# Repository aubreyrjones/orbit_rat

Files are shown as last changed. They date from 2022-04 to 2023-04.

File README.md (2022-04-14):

Orbit Rat
---------
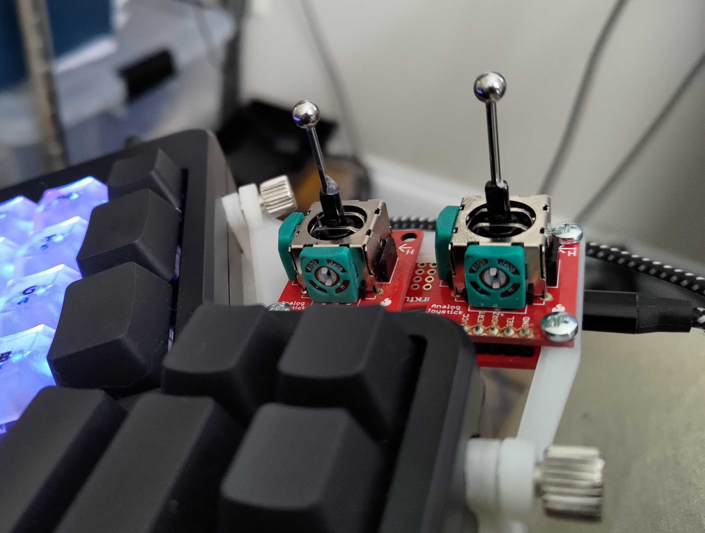
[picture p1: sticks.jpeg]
Orbit Rat prototype


[Watch a demo](https://www.youtube.com/watch?v=k3nQiXu3pM4)

THIS IS NOT A MOUSE REPLACEMENT. The Orbit Rat is a Teensy LC based PC input device designed
to facilitate panning and orbiting in CAD and graphic design software.

The concept is similar to the 3dconnexion navigation device. But the Orbit Rat has fewer 
degrees of freedom, much wider compatibility, and much lower cost. The Orbit Rat is not 
quite a space mouse, you see.

The OR is designed around a pair of small joysticks, like those on a gamepad controller. These 
joysticks then control pan and orbit in CAD, art, and graphic design programs by specially
emulating a mouse. _No special drivers or plugins needed_, works in any operating system.

This is not a regular joystick-controlled mouse. OR implements a special "rewind" operation
after every motion, which resets the mouse cursor position and unlocks near-infinite pan/orbit 
in any program that uses middle-click and drag for pan.

The cost to build one is around $30 USD. You could build it without any soldering, using
breadboard, but it will be bulky. You can easily solder it on protoboard with hand wiring.
It's also an easy circuit board to design.

Tested on Linux and Windows. Should work on Mac and mobile OS as well.

Tested to work with default settings in:

* Fusion 360
* Inkscape
* GIMP
* EAGLE CAD

# How it Works

This is pretty configurable, but by default...

When you tilt the stick outside the deadzone, Orbit Rat emulates a mouse holding down the middle
mouse button and starting a drag motion. This starts a pan action in lots of CAD and art software. 
The viewport will move as if you're panning with the mouse so long as you're tiling the stick.

If you think about how your favorite software works, when you finish the pan motion and let go the button,
the mouse is in a different part of the screen than when you started. You have to 
move the cursor back toward the middle of the screen to get more space if you want to continue the pan. 
With a traditional joystick-controlled mouse, this is torture.

But not so with Orbit Rat.

As you move, the OR tracks how much mouse motion it has sent to your computer. When you let
go of the stick, it very quickly moves the cursor back to where it was when you first tilted the stick. 
You can now continue the pan just by tilting the stick again. Or, you can continue your work 
with the cursor just where you left it.

The other stick works very similarly, but also emulates holding down the left shift keyboard button. 
This will activate an orbit in CAD software.

This is almost as much control as a dedicated "3d mouse" with special driver support. The beauty of 
Orbit Rat is that it works everywhere, in any operating system, in any application that uses click 
and drag for pan.

It can also do other stuff, like sending scroll wheel events and keyboard keys... but the rewind
operation is what it does uniquely.

# Features

* User defined list of stick modes and parameters to use. As many as you like until
  you run out of RAM. Most of what's discussed below can be set per mode.

* Cycle through your defined modes by clicking the stick buttons.

* REWIND - stick initiates a mouse movement, then OR returns the cursor to its starting
  position when you let go of the stick.

* STUTTER - similar to rewind mode, but continually moves a set distance, rewinds, then 
  repeats as long as you hold down the button. Not smooth, but allows "infinite" scrolling
  with limited screen real estate.

* SIMPLE - just be a mouse cursor, no rewind.

* SCROLL - stick movement sends scroll wheel commands. Useful for CAD zoom, or
  document scrolling.

* User-defined stick curves, so you can tweak the sensitivity of each stick.

* Invert or ignore any stick axis.

* Choose mouse button(s) and/or keyboard key that is held during mouse motion.

* Auto-calibrates joysticks by default (although not perfectly)

* Configurable to send HID joystick events if desired for custom application code.

* Parts are available circa Q2 2022. Teensy LC available despite chip shortage. 
  Joysticks and other parts available from hobby electronics suppliers (Sparkfun, 
  Adafruit).

# _Planned_ Features

* RGB status LEDs (DotStar) for each stick's modes
* PCB reference design
* Left-handed PCB design

# Limitations

The Orbit Rat is fundamentally impersonating a mouse, so it doesn't have access to any
information a regular dumb mouse wouldn't have. It doesn't get any feedback from the 
operating system.

The main place this shows up is when the cursor hits the edge of the screen during a move.
The Orbit Rat thinks it's still moving the cursor, but the OS doesn't let it leave the screen.
When the OR goes to rewind the cursor motion at the end of the move, it has the wrong
idea of how much to rewind and overshoots.

Additionally, moue wheel scrolling in Linux and Windows is _not_ smooth. It goes in
chunky, discrete increments. Orbit Rat tries its best to send scroll events at a steady
rate, but without special drivers, it can't make the screen animation smooth when
scrolling (like e.g. Apple trackpad scrolling).

# Configuration and Building

Since you need the tools to upload the firmware anyway, I made things easy for me.
Orbit Rat is configured in source code and built with [PlatformIO](https://platformio.org/).

The easiest way to use PlatformIO is just to use VisualStudio Code (not Visual Studio) with
the free PlatformIO plugin from the marketplace. Standalone setups may work but I haven't
tested them.

When you first build, it may seem to stall for a very long time. PlatformIO is downloading a newer
compiler from a very slow connection. It gives no progress indicator. It seriously
took me 20 minutes to download. This only happens the first time you build. It also
may finish the download, try to compile, then say it failed... try again before
concluding it doesn't work.

Configuration is at the top of `main.cpp`. You can learn more about the options in 
`config_types.hpp`.

On your operation system you will need to set the "Teensyduino OrbitRat Mouse" acceleration
to 0. If you don't, the cursor will not return to the correct location. You should be able
to leave acceleration on for your regular mouse however you like it.

## Hardware

This isn't commercial hardware or software. You'll need to cobble together your
own hardware setup.

I'm using a Teensy LC as my microcontroller. I expect Teensy 4.0 would work, but
little is gained from its expanded capabilities. Teensy 3 might work; Teensy 2
is not compatible.

Assuming you'll use the software mostly unmodified, you need to hook up a pair of
potentiometer joysticks to the Teensy's analog inputs. That's pretty much it.

For the prototype I used the model of joystick sold on SparkFun, along with their 
breakout boards. I wired up the axes directly to the Teensy LC analog pins. I added 
pullup resistors on the switches There are internal pullups that could work, but I 
didn't test that way.

You can see my pin assignments in `main.cpp` under `axisPins` and `buttonPins`.
That's also where you can alter them if you'd like to wire the pins up differently.
Note that you _must_ use analog inputs for the joysticks.

## Software

The software isn't written to be especially efficient. It's written for a Teensy LC,
which has a 48MHz core clock. I haven't noticed that input rates are too low, so
I don't worry about a bit of fake floating point.

Calibration is quasi-automatic right now (although you can turn it off). By default, 
the center point is read at startup. Conservative endpoints are taken as a default,
but will expand if they receive a higher value from the hardware during operation. You 
can turn off both these features at the top of `main.cpp`.

## Troubleshooting

> Problem: I flashed the firmware and plugged it into the computer, but my mouse doesn't 
work or moves erratically.

This is "normal" if you flash the Teensy with Orbit Rat firmware, but have not attached
the joysticks to it. Without the joysticks, the Teensy input voltages drift randomly
and result in erratic movement. Ideally, install both joysticks. If you need just
one joystick for some reason, adjust `n_axes` to equal `2` and fix the resultant
compile errors.

## This is not a commercial venture, and the Orbit Rat is not for sale

The whole point of the project is that it's very, very cheap compared to the pro-grade
alternative. Stocking the parts, assembling them, and shipping them takes time
I have no interest in spending. And people have expectations of commercial products
(warranties, returns, etc.) that I don't want to deal with. I have a job, and a
few bucks just isn't worth the hassle.

To make it worth it to me, each unit would need to sell for $100 or more. And
that kind of defeats the purpose.

On the other hand, this is also an absolutely _ideal_ first microcontroller project.
You can build a completely decent version using just breakout- and bread-boards.
It is within your abilities to Orbit Rat. I believe in you.

You can also try one of the circuit boards from the `circuits` directory.
Most of those designs aren't tested, but they're a good starting point for
your design. When I get a design printed and tested, I will mark it 
conspicuously.

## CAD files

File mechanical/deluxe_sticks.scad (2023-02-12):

$fn = 80;

bottom_height = 2;
main_height = 14;

clearance_diam = 5;
bottom_diam = 5;
top_diam = 12;
ball_diam = top_diam;
top_height = 12 - (ball_diam / 2);

stem_width = 1.85;
stem_thickness = 1.15;
stem_depth = 5;
stem_slop = 1.05;

module stick() {
difference() {
    union() {
        cylinder(bottom_height, d1= clearance_diam, d2 = bottom_diam);
        translate([0, 0, bottom_height])
            cylinder(main_height, d1 = bottom_diam, d2 = top_diam);
        translate([0, 0, main_height + bottom_height]) {
            cylinder(top_height, d = top_diam);
        }
        translate([0, 0, main_height + top_height + bottom_height]) {
            sphere(d = ball_diam);
        }
    }
    
    union() {
        translate([0, 0, stem_depth / 2]) 
            cube([stem_width * stem_slop, stem_thickness * stem_slop, stem_depth * 1.05], center = true);
    }
} 
}

$start_radius = 0.5;
$tip_radius = 0.2;
$tip_height = 1;
$full_support_height = 0.42;
$debug_supports = false;
$base_radius = $debug_supports ? $start_radius : $start_radius * 6.5;



module one_support(position, height) {
    transition_point = height - $tip_height;
    color([1, 0, 0]) union() {
        translate(position) {
            cylinder(0.20, $base_radius, $base_radius, false);
            cylinder(transition_point, $start_radius, $start_radius, false);
            translate([0, 0, transition_point]) {
                cylinder($tip_height, $start_radius, $tip_radius, false);
            }
        }
    }
}

support_height = 3;
s_off = (bottom_diam / 2) - ($tip_radius * 2);

stick();

//union() {
//    stick();
//    translate([0, 0, -support_height]) {
//        for (x = [-1.35, 1.35]) {
//            for (y = [-1.35, 1.35]) {
//                one_support([x, y], support_height);
//            }
//        }
//        one_support([0, s_off], support_height);
//        one_support([0, -s_off], support_height);
//        one_support([s_off, 0], support_height);
//        one_support([-s_off, 0], support_height);
//    }
//}

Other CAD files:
mechanical/plastic_sticks.scad

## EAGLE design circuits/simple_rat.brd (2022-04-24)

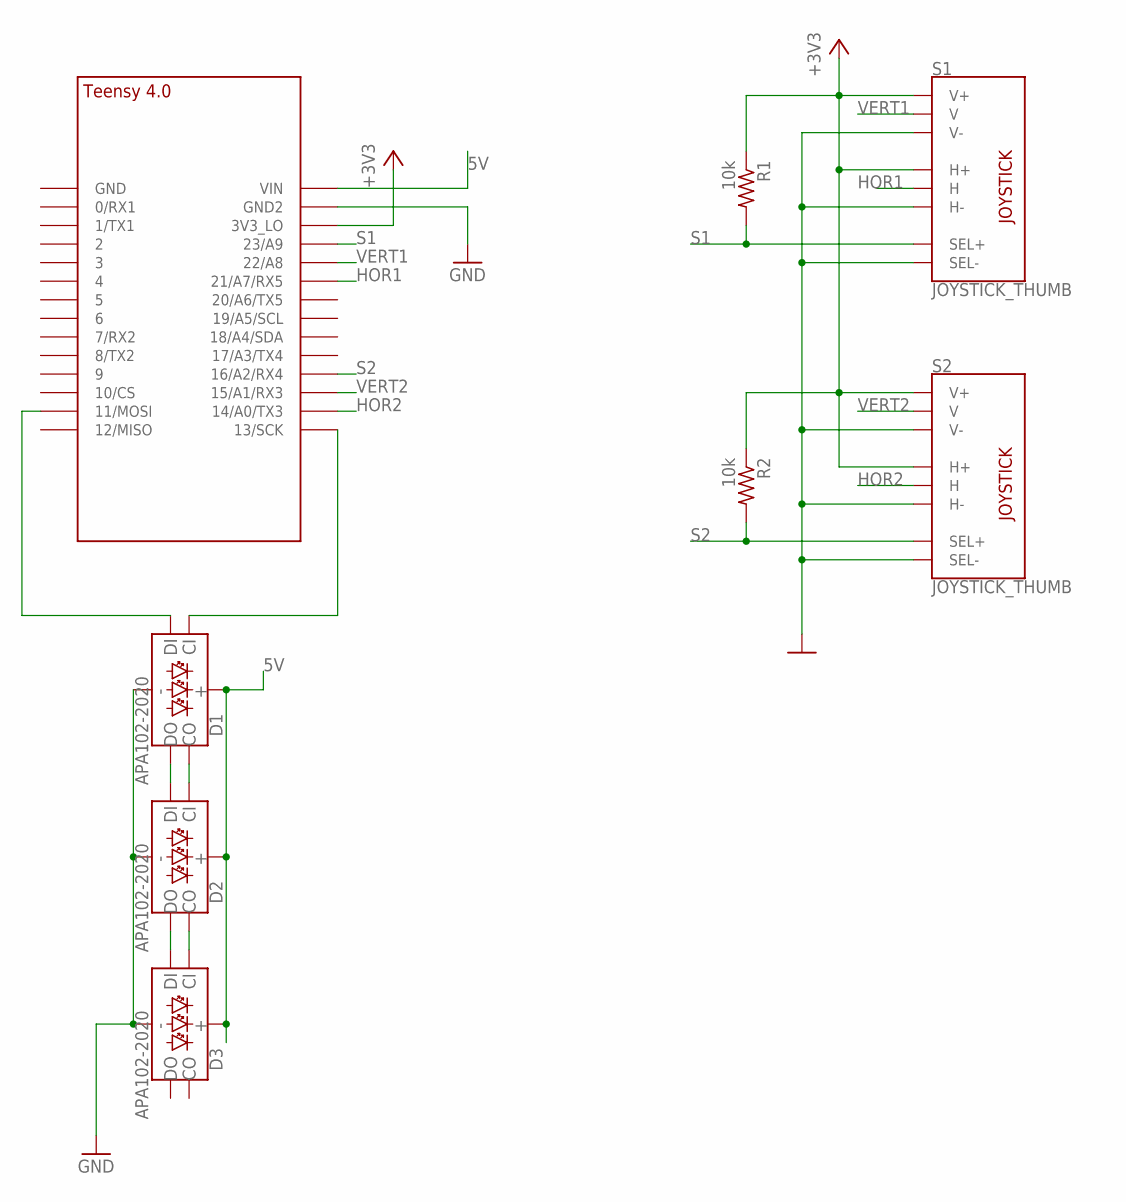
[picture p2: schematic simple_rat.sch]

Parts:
D1, D2, D3: APA102-2020
MCU: TEENSY_4.0-NOBOTTOM
R1, R2: 10k; R0603
S1, S2: JOYSTICK_THUMB; JOYSTICK

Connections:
5V: D1.5V_VIA (VCC), D1.VDD (VCC), D2.5V_VIA (VCC), D2.VDD (VCC), D3.5V_VIA (VCC), D3.VDD (VCC), MCU.VIN
+3V3: MCU.3V3_LO, R1.1, R2.1, S1.H1 (H+), S1.V1 (V+), S2.H1 (H+), S2.V1 (V+)
GND: D1.GND, D1.GND_VIA (GND), D2.GND, D2.GND_VIA (GND), D3.GND, D3.GND_VIA (GND), MCU.GND2, S1.B2A (SEL-), S1.H3 (H-), S1.V3 (V-), S2.B2A (SEL-), S2.H3 (H-), S2.V3 (V-)
HOR1: MCU.21/A7 (21/A7/RX5), S1.H2 (H)
HOR2: MCU.14/A0 (14/A0/TX3), S2.H2 (H)
unnamed: D1.SDO (DO), D2.SDI (DI)
unnamed: D1.CKO (CO), D2.CKI (CI)
unnamed: D2.SDO (DO), D3.SDI (DI)
unnamed: D2.CKO (CO), D3.CKI (CI)
unnamed: D1.CKI (CI), MCU.13/SCK
unnamed: D1.SDI (DI), MCU.11/MOSI
S1: MCU.23/A9, R1.2, S1.B1A (SEL+)
S2: MCU.16/A2 (16/A2/RX4), R2.2, S2.B1A (SEL+)
VERT1: MCU.22/A8, S1.V2 (V)
VERT2: MCU.15/A1 (15/A1/RX3), S2.V2 (V)

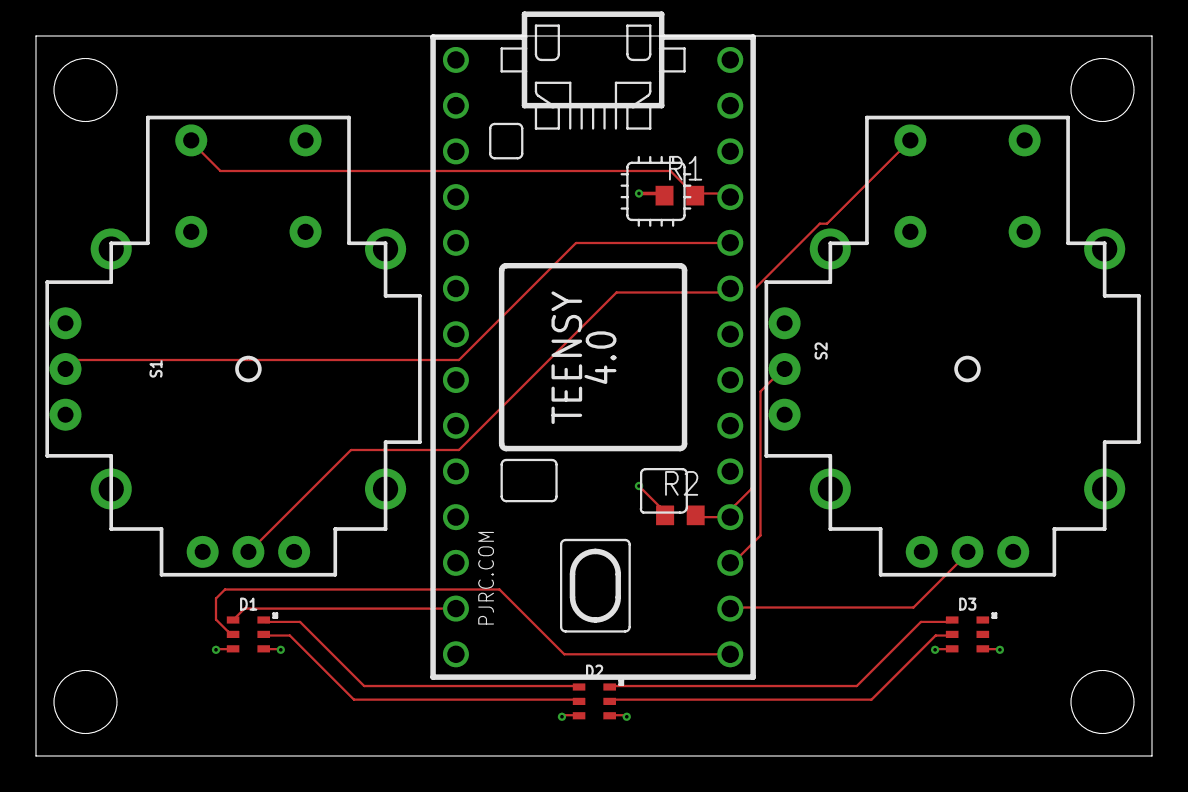
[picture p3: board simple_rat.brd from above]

Board: 4 copper layers, 62.0 x 40.0 mm, 8 parts (0 on the bottom side), 15 nets.

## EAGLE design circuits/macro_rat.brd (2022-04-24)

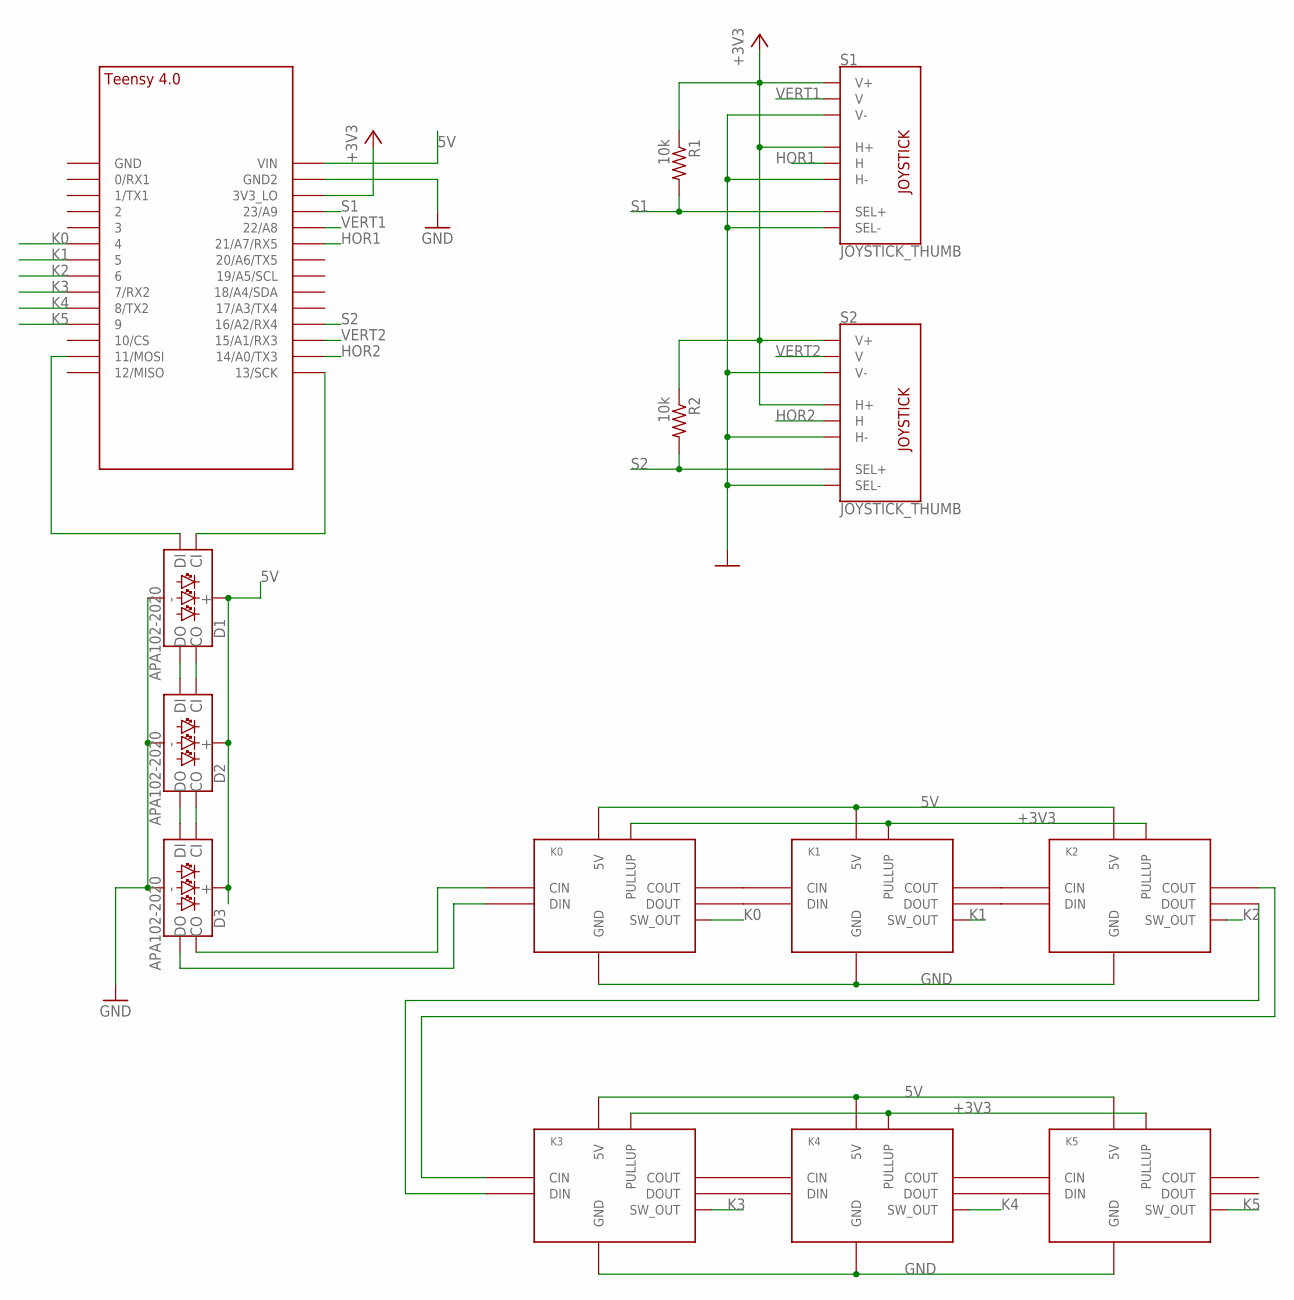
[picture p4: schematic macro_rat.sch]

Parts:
D1, D2, D3: APA102-2020
K0, K1, K2, K3, K4, K5: KEY_LED_CHOC_ONESIDERIGHT_HAND; KEY_CHOC_V2_RH
MCU: TEENSY_4.0-NOBOTTOM
R1, R2: 10k; R0603
S1, S2: JOYSTICK_THUMB; JOYSTICK

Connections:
5V: D1.5V_VIA (VCC), D1.VDD (VCC), D2.5V_VIA (VCC), D2.VDD (VCC), D3.5V_VIA (VCC), D3.VDD (VCC), K0.5V, K0.VDD (5V), K1.5V, K1.VDD (5V), K2.5V, K2.VDD (5V), K3.5V, K3.VDD (5V), K4.5V, K4.VDD (5V), K5.5V, K5.VDD (5V), MCU.VIN
+3V3: K0.PULLUP_V (PULLUP), K0.PULLUP_VIA (PULLUP), K1.PULLUP_V (PULLUP), K1.PULLUP_VIA (PULLUP), K2.PULLUP_V (PULLUP), K2.PULLUP_VIA (PULLUP), K3.PULLUP_V (PULLUP), K3.PULLUP_VIA (PULLUP), K4.PULLUP_V (PULLUP), K4.PULLUP_VIA (PULLUP), K5.PULLUP_V (PULLUP), K5.PULLUP_VIA (PULLUP), MCU.3V3_LO, R1.1, R2.1, S1.H1 (H+), S1.V1 (V+), S2.H1 (H+), S2.V1 (V+)
GND: D1.GND, D1.GND_VIA (GND), D2.GND, D2.GND_VIA (GND), D3.GND, D3.GND_VIA (GND), K0.GND, K0.GND$1 (GND), K0.GND$2 (GND), K0.GND$3 (GND), K0.GND$4 (GND), K0.GND_VIA (GND), K1.GND, K1.GND$1 (GND), K1.GND$2 (GND), K1.GND$3 (GND), K1.GND$4 (GND), K1.GND_VIA (GND), K2.GND, K2.GND$1 (GND), K2.GND$2 (GND), K2.GND$3 (GND), K2.GND$4 (GND), K2.GND_VIA (GND), K3.GND, K3.GND$1 (GND), K3.GND$2 (GND), K3.GND$3 (GND), K3.GND$4 (GND), K3.GND_VIA (GND), K4.GND, K4.GND$1 (GND), K4.GND$2 (GND), K4.GND$3 (GND), K4.GND$4 (GND), K4.GND_VIA (GND), K5.GND, K5.GND$1 (GND), K5.GND$2 (GND), K5.GND$3 (GND), K5.GND$4 (GND), K5.GND_VIA (GND), MCU.GND2, S1.B2A (SEL-), S1.H3 (H-), S1.V3 (V-), S2.B2A (SEL-), S2.H3 (H-), S2.V3 (V-)
HOR1: MCU.21/A7 (21/A7/RX5), S1.H2 (H)
HOR2: MCU.14/A0 (14/A0/TX3), S2.H2 (H)
K0: K0.OUT (SW_OUT), K0.OUT_UP (SW_OUT), MCU.4/CANRX (4)
K1: K1.OUT (SW_OUT), K1.OUT_UP (SW_OUT), MCU.5
K2: K2.OUT (SW_OUT), K2.OUT_UP (SW_OUT), MCU.6
K3: K3.OUT (SW_OUT), K3.OUT_UP (SW_OUT), MCU.7 (7/RX2)
K4: K4.OUT (SW_OUT), K4.OUT_UP (SW_OUT), MCU.8 (8/TX2)
K5: K5.OUT (SW_OUT), K5.OUT_UP (SW_OUT), MCU.9/CS (9)
unnamed: K0.CKO (COUT), K1.CKI (CIN)
unnamed: K0.SDO (DOUT), K1.SDI (DIN)
unnamed: K1.CKO (COUT), K2.CKI (CIN)
unnamed: K1.SDO (DOUT), K2.SDI (DIN)
unnamed: K3.CKO (COUT), K4.CKI (CIN)
unnamed: K3.SDO (DOUT), K4.SDI (DIN)
unnamed: K4.CKO (COUT), K5.CKI (CIN)
unnamed: D1.SDO (DO), D2.SDI (DI)
unnamed: D1.CKO (CO), D2.CKI (CI)
unnamed: D2.SDO (DO), D3.SDI (DI)
unnamed: D2.CKO (CO), D3.CKI (CI)
unnamed: D1.CKI (CI), MCU.13/SCK
unnamed: D1.SDI (DI), MCU.11/MOSI
unnamed: K4.SDO (DOUT), K5.SDI (DIN)
unnamed: D3.CKO (CO), K0.CKI (CIN)
unnamed: D3.SDO (DO), K0.SDI (DIN)
unnamed: K2.SDO (DOUT), K3.SDI (DIN)
unnamed: K2.CKO (COUT), K3.CKI (CIN)
S1: MCU.23/A9, R1.2, S1.B1A (SEL+)
S2: MCU.16/A2 (16/A2/RX4), R2.2, S2.B1A (SEL+)
VERT1: MCU.22/A8, S1.V2 (V)
VERT2: MCU.15/A1 (15/A1/RX3), S2.V2 (V)

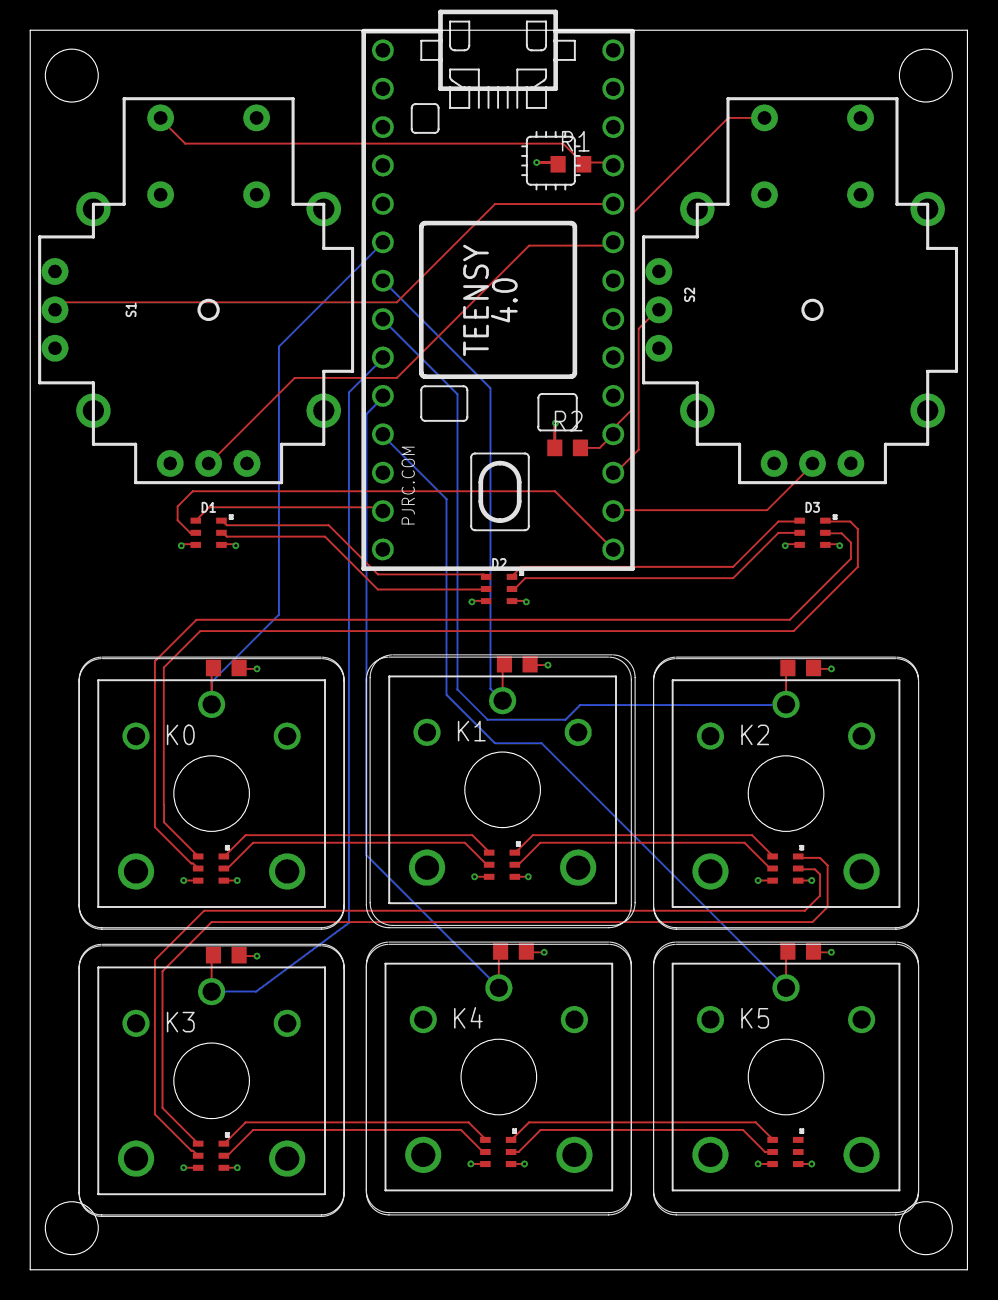
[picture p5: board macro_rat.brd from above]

Board: 4 copper layers, 62.0 x 82.0 mm, 14 parts (0 on the bottom side), 33 nets.

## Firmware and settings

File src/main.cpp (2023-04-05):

#include <Arduino.h>
#include <Keyboard.h>
#include <Bounce2.h>
#include <Metro.h>
#include <functional>
#include <Adafruit_DotStar.h>
#include "config_types.hpp"

/**
 * BEGIN CONFIGURATION
*/

#define SUPPORT_RAT_DRIVER // comment out this line if you want to disable host driver support.

// stick -> motion curves you'll reference in your StickModes. Tweak these and make more if you want.
constexpr auto panCurve = make_curve(25); // maximum movement speed, linear curve
constexpr auto orbitCurve = make_curve(10, 0.5); // max speed with slight "expo" factor
constexpr auto zoomScrollCurve = make_curve(1400, 0.6); // note that scroll speed is on a different order of magnitude, also major expo

// set up the list of stick modes for each axis.
// note the fancy named initializer list thingie. Note that even if there are gaps, fields must be referenced
// in the order they're defined. Check `config_types.hpp` for details.
constexpr auto stickModes = declare_mode_map(
  std::array { // stick 0
    StickMode { MovementMode::REWIND, panCurve,  .indicator = rgb(50, 0, 0), {false, true, false} },
    StickMode { MovementMode::STUTTER, panCurve, .indicator = rgb(0, 50, 0), {false, true, false}, .motionThreshold = 25 },
    StickMode { MovementMode::STUTTER, panCurve, .indicator = rgb(0, 0, 50), {false, false, true} }
  },
  std::array { // stick 1
    StickMode { MovementMode::SCROLL, zoomScrollCurve, .indicator = rgb(50, 0, 0), .horDir = NULL_AXIS},
    StickMode { MovementMode::REWIND, orbitCurve,      .indicator = rgb(0, 50, 0), {false, true, false}, KEY_LEFT_SHIFT },
    StickMode { MovementMode::REWIND, orbitCurve,      .indicator = rgb(0, 0, 50), {true, false, false}}
  }
);

#ifdef SUPPORT_RAT_DRIVER
// when the driver is in use, these stick modes define the motion behavior for dynamic modes.
// the actual buttons clicked/held will be adjusted via messages from the driver.
// If you're not using the driver, you can leave these alone.
auto dynamicModes = std::array {
  StickMode { MovementMode::STUTTER, panCurve}, // dynamic pan
  StickMode { MovementMode::REWIND, orbitCurve}, // dynamic orbit
  StickMode { MovementMode::SCROLL, zoomScrollCurve, .horDir = NULL_AXIS} // dynamic zoom
};
#endif 

// global mouse/stick behavior options

constexpr float deadzone = 0.08; // absolute normalized axis value must be above this to be considered active
constexpr int max_unwind_step = 100; // how many pixels per HID report to move the mouse during unwinding
constexpr int stutter_step = 1000; // how far to move the cursor in stutter mode before stuttering back.
constexpr int button_debounce_interval = 25; // how many ms any button needs to be held for to register.
constexpr int mouse_interval = 10; // minimum interval between mouse motion updates, in ms. (not recommended to change)
// note that changing the mouse_interval will affect all mouse and scrolling speeds

// Key macros.

constexpr uint32_t macroColors[] = {
  rgb(0x42, 0xFF, 0x00),
  rgb(0x42, 0xFF, 0x00),
  rgb(0x42, 0xFF, 0x00),
  rgb(50, 0, 50),
  rgb(50, 0, 50),
  rgb(50, 0, 50)
};

using MacroFunction = std::function<void(bool)>;
const std::array<MacroFunction, 6> buttonMacros = {
  [](bool pressed) {
    if (pressed) {
      Mouse.press(MOUSE_RIGHT);
    }
    else {
      Mouse.release(MOUSE_RIGHT);
    }
  },

  [](bool pressed) {
    if (pressed) {
      Mouse.press(MOUSE_MIDDLE);
    }
    else {
      Mouse.release(MOUSE_MIDDLE);
    }
  },

  [](bool pressed) {
    if (pressed) {
      Mouse.press(MOUSE_LEFT);
    }
    else {
      Mouse.release(MOUSE_LEFT);
    }
  },

  [](bool pressed) {
    if (pressed) {
      Keyboard.press(KEY_LEFT_SHIFT);
    }
    else {
      Keyboard.release(KEY_LEFT_SHIFT);
    }
  },
  
  [](bool pressed) {
    if (pressed) {
      Keyboard.press(KEY_LEFT_ALT);
    }
    else {
      Keyboard.release(KEY_LEFT_ALT);
    }
  },

  [](bool pressed) {
    if (pressed) {
      Keyboard.press(KEY_LEFT_CTRL);
    }
    else {
      Keyboard.release(KEY_LEFT_CTRL);
    }
  }
};


// firmware behavior.

#ifdef SUPPORT_RAT_DRIVER
constexpr bool support_driver = true; // turn on firmware support for the `rat_tail` driver program
#else
constexpr bool support_driver = false;
#endif

/* calibration options */
constexpr bool center_on_startup = true; // record startup reading from sticks as center value?
constexpr bool autocal = true; // attempt to automatically calibrate during use.

/* HID joystick options */
constexpr bool send_joystick_hid = true; // (also) send HID joystick records for the sticks and buttons?
constexpr int joystick_interval = 10; // minimum interval between joystick HID reports, in ms.

/* USB serial options */
constexpr bool serial_status_reports = false; // (also) output structured serial reports
constexpr bool serial_raw_axes = false; // report raw axis values
constexpr bool serial_norm_axes = false; // report normalized axis values
constexpr bool serial_buttons = true; // report button presses
constexpr int serial_interval = 100; // minimum interval between serial axis reports, in ms
/**
 * Serial reports are of the formats:
 * AXES a0 a1 a2 ...   // raw axis values, from 0 to 1023.
 * NORM a0 a1 a2 ...   // normalized axis values, from -100 to +100.
 * BP index             // `index` button was pressed
 * BR index             // `index` button was released
*/

/* HARDWARE CONFIGURATION */

constexpr int macroKeyCount = 6; // number of macro keys.

/**
 * Axis, stick, and button ordering:
 * 
 * Sticks are made up of consecutive pairs of axes. First the X axis for that stick, then the Y axis.
 * So stick 0 is made of axis 0 (x) and axis 1 (y), stick 1 is axis 2 (x) and axis 3 (y), etc.
 * 
 * The first two buttons are the integrated buttons for stick 0 and stick 1 respectively.
**/

constexpr int n_axes = 4; // number of axes we're going to sample. Every pair of axes is a "stick".

// calibration: low value, center, high value.
// note that this is intentionally not `constexpr` to permit live calibration.
int16_t axisExtents[][3] = {
  {10, 520, 1015},
  {10, 498, 1015},
  {10, 530, 1015},
  {10, 513, 1015}
};

// for each axis, set inversion mode. This should be set up so that the joystick reports
// match the physical stick directions. Do not use this configuration value to control
// the direction of mouse motion relative to the stick--use .vertDir and .horDir in
// your StickMode to control the mouse motion inversion.
// Basically, use these inversions to compensate for how you've mounted/rotated
// your sticks.
constexpr int8_t axisInvert[] = {
  INVERT_AXIS, INVERT_AXIS, INVERT_AXIS, INVERT_AXIS
};

// stuff below here requires different hardware than OrbitRat is designed for. It's useful
// if you're trying to hack this software to support new input devices or
// if you built your rat differently than I do.

// pin assignments

// Which pin goes to which axis? These are Teensy ANALOG pin numbers.
constexpr uint8_t axisPins[] = {
  // 1, 0, 8, 7    // breadboard rat
  7, 8, 0, 1       // pcb rat
};

// Which LED indices go with the sticks?
constexpr uint8_t stickLEDs[] = {
  0, 2
};

constexpr int n_buttons = 2 + macroKeyCount; // number of buttons

// which pins are buttons attached to? These are Teensy DIGITAL pin numbers.
// first two pins listed should be for the buttons _on_ stick 0 and stick 1.
// the rest are for the macro buttons.
// something neat! since this is constexpr, and `n_buttons` is also const
// the compiler seems to know that the unused values aren't referenced and
// doesn't keep them in the table if you have the macros disabled.
constexpr uint8_t buttonPins[] = { 
  //16, 23, 0       // breadboard rat
  23, 16,      // pcb rat
  4, 5, 6, 7, 8, 9 // macro rat
};

// Which LED index is the first of the macro keys?
constexpr uint8_t buttonLEDMap[] = {
  0, 2, 
  3, 4, 5, 6, 7, 8
};

/**
 * END CONFIGURATION
*/



// raw state sampled from analog inputs
int16_t axisValues[n_axes] = {0, 0, 0, 0};

// button debouncers
std::array<Bounce, n_buttons> buttons {};

// button state
std::array<bool, n_buttons> buttonState {};

// button colors before they're turned off during press.
std::array<uint32_t, n_buttons> buttonColorCache {};

// axis values in the range (-1, 1)
std::array<float, n_axes> normalizedAxes{};

// LEDs
Adafruit_DotStar ledStrip(9, 11, 13, DOTSTAR_BRG);

// forward declaration
void doUnwind(int unwindAccumulator[2]);

template <typename T>
constexpr bool eitherMagAbove(T vec[2], T threshold){
  return abs(vec[0]) >= threshold || abs(vec[1]) >= threshold;
}

// sample a curve from a stick position and return the value.
StickCurve::value_type sampleExpoCurve(StickCurve const& curve, float pos) {
  int point = abs(pos * (curve.size() - 1));
  auto sign = pos >= 0 ? 1 : -1;
  return curve[point] * sign;
}


// primary stick handler class
struct StickState {
  const int index; // which stick is this?
  const int xAxis, yAxis; // which axes are we using?

  int activeStickMode = 0; // which mode in the mode map are we using now?

  int moveAccum[2] = {0, 0}; // accumulates unsent motion, used to smooth motion and reduce errant clicks
  int scrollAccum[2] = {0, 0}; // accumulates scrolling motion, which is converted into distinct mousewheel clicks
  int unwindAccum[2] = {0, 0}; // accumulates _sent_ motion, used to unwind the cursor position.
  
  bool stickActive = false; // is the stick currently in control?
  bool buttonsActivated = false; // are we currently holding down mousebuttons and keys?

  StickState(int index) : index(index), xAxis(index * 2), yAxis(index * 2 + 1) {}

  // advance the active mode by one, looping around at the end.button
  void advanceActiveMode() {
    activeStickMode = (activeStickMode + 1) % stickModes.count(index);
    updateStickLED();
  }

  void updateStickLED() {
    ledStrip.setPixelColor(stickLEDs[index], mode().indicator);  
  }

  float x() const { return normalizedAxes[xAxis]; }
  float y() const { return normalizedAxes[yAxis]; }


  // Checks whether the stick is in the deadzone.
  bool checkDeadzone() {
    return abs(x()) < deadzone && abs(y()) < deadzone;
  }

  // gets the current mode
  StickMode const& mode() {
    return stickModes.getMode(index, activeStickMode);
  };

  // clears all the motion accumulators.
  void clearMotion() {
    unwindAccum[0] = unwindAccum[1] = 0;
    moveAccum[0] = moveAccum[1] = 0;
    scrollAccum[0] = scrollAccum[1] = 0;
  }

  // presses down buttons and keys prior to active motion
  void precedeActiveMotion(){
    if (buttonsActivated) return;

    setKeys(true);
    if (mode().hasButtons()) {
      Mouse.set_buttons(mode().activeButtons[0], mode().activeButtons[1], mode().activeButtons[2]);
      delay(10);
    }
    buttonsActivated = true;
  }

  // releases buttons and keys after active motion
  void endActiveMotion() {
    if (!buttonsActivated) return;

    if (mode().hasButtons()) {
      Mouse.set_buttons(0, 0, 0);
      delay(10);
    }
    setKeys(false);
    buttonsActivated = false;
  }

  // call this when this stick is active and controlling the cursor.
  void activate() {
    clearMotion();
    stickActive = true;
  }

  // call this when the stick is done.
  void deactivate() {
    endActiveMotion();
    switch (mode().move) {
      case MovementMode::REWIND:
      case MovementMode::STUTTER:
        unwindMotion();
        break;
      default:
        break;
    }

    stickActive = false;
  }

  // stutters the mouse back to continue an active move.
  void stutterBack() {
    endActiveMotion();
    //delay(25);
    unwindMotion();
  }

  // send the mouse cursor motion if it's above the motionThreshold.
  void sendMotion() {
    if (eitherMagAbove(moveAccum, mode().motionThreshold)) {
      precedeActiveMotion();
      int xMove = (int) moveAccum[0];
      int yMove = (int) moveAccum[1];

      Mouse.move(xMove, yMove);
      unwindAccum[0] += xMove;
      unwindAccum[1] += yMove;
      moveAccum[0] -= xMove;
      moveAccum[1] -= yMove;
    }
  }

  // integrate stick and speed into the given accumulator.
  template <typename T>
  void accumulateMotion(T acc[2]) {
    auto const& curve = mode().curve;
    acc[0] += sampleExpoCurve(curve, x()) * mode().horDir;
    acc[1] += sampleExpoCurve(curve, y()) * mode().vertDir;
  }

  // update mouse motion from the sticks axes.
  void moveMouseMotion() {
    accumulateMotion(moveAccum);
    sendMotion();

    if (mode().move == MovementMode::STUTTER) {
      if (eitherMagAbove(unwindAccum, stutter_step)) {
        stutterBack();
      }
    }
    else if (mode().move == MovementMode::CHASE) {
      if (eitherMagAbove(unwindAccum, 25)) {
        Keyboard.set_modifier(mode().chaseMods);
        Keyboard.set_key1(mode().chaseKey);
        Keyboard.send_now();

        Keyboard.set_key1(0);
        Keyboard.set_modifier(0);
        Keyboard.send_now();
        
        stutterBack();
      }
    }
  }

  // the scroll accumulator has to get this magnitude to trigger a scroll wheel click
  static constexpr int scroll_saturate = 10000;

  // Updates the given directional scroll, and returns +/-1 to indicate the mouse wheel should click.
  int getDirectionScroll(int index) {
    auto sv = scrollAccum[index];
    auto sign = sv >= 0 ? 1 : -1;

    if (abs(sv) >= scroll_saturate) {
      scrollAccum[index] -= sign * scroll_saturate;
      return sign;
    }
    return 0;
  }

  // update scrolling based on stick axes.
  void moveScrollMotion(bool firstMove) {
    accumulateMotion(scrollAccum);
    if (firstMove) { // force a move on the first step
      for (int & s : scrollAccum) {
        if (s < 0) {
          s += -scroll_saturate;
        }
        else if (s > 0) {
          s += scroll_saturate;
        }
      }
    }
    int scrollX = getDirectionScroll(0), scrollY = getDirectionScroll(1);
    if (scrollX || scrollY) {
      Mouse.scroll(scrollY, scrollX);
    }
  }

  // integrated update function that handles all movement modes.
  void moveActiveMotion(bool firstMove = false) {
    switch (mode().move){
      case MovementMode::SCROLL:
        moveScrollMotion(firstMove);
        break;
      default:
       moveMouseMotion();
    }
    //delay(10);
  }

  // unwind sent cursor motion to return the cursor to its start position
  void unwindMotion() {
    doUnwind(unwindAccum);
  }

  // hold down the mode's keys.
  void setKeys(bool press) {
    auto key = mode().activeKey;
    
    if (!key) return;

    if (press) {
      Keyboard.press(key);
    }
    else {
      Keyboard.release(key);
    }

    delay(10);
  }
};

StickState sticks[n_axes / 2] = {
  StickState(0),
  StickState(1)
};

// read the analog sticks.
void readSticks() {
  for (int i = 0; i < n_axes; i++) {
    axisValues[i] = analogRead(axisPins[i]);
  }
}

// normalize the value within the half space.
float normalize(float low, float val, float high) {
  auto range = high - low;
  return (val - low) / range;
}

// convert the normalized stick values to the 0-1023 values for the joystick system.
unsigned int to_joy(float val) {
  return (unsigned int) ((val + 1.f) / 2.f * 1023);
}

// Normalize the raw values read from the analog sticks.
void normalizeSticks() {
  for (int i = 0; i < n_axes; i++) {
    if (axisValues[i] < axisExtents[i][1]) { // which half of the stick are we on?
      if (axisValues[i] < axisExtents[i][0]) { // are we oversaturated?
        if constexpr (autocal) { // if we're in autocal mode, change the limit
          axisExtents[i][0] = axisValues[i];
        }
        else {
          axisValues[i] = axisExtents[i][0]; // if we're not in autocal, just clamp it.
        }
      }

      normalizedAxes[i] = -1 + normalize(axisExtents[i][0], axisValues[i], axisExtents[i][1]);
    }
    else {  
      if (axisValues[i] > axisExtents[i][2]) { // oversatured?
        if constexpr (autocal) {
          axisExtents[i][2] = axisValues[i];
        }
        else {
          axisValues[i] = axisExtents[i][2];
        }
      }
      
      normalizedAxes[i] = normalize(axisExtents[i][1], axisValues[i], axisExtents[i][2]);
    }

    normalizedAxes[i] = axisInvert[i] * normalizedAxes[i]; // invert all channels to get normalized motion.
  }
}

// Send joystick updates.
void sendJoystick() {
  Joystick.X(to_joy(normalizedAxes[0]));
  Joystick.Y(to_joy(normalizedAxes[1]));
  Joystick.sliderLeft(to_joy(normalizedAxes[3]));
  Joystick.Zrotate(to_joy(normalizedAxes[2]));
}

// When we unwind the mouse motion, find the largest step we can move
// to reduce the given accumulator. This is necessary because the
// teensy HID system only spec's mouse moves between -127 and 127.
int max_step(int const& accum) {
  if (accum > 0) {
    return -min(accum, max_unwind_step);
  }
  else if (accum < 0) {
    return min(max_unwind_step, -accum);
  }

  return 0;
}

// Move the mouse back to its start point.
void doUnwind(int unwindAccumulator[2]) {
  while (unwindAccumulator[0] != 0 || unwindAccumulator[1] != 0) {
    int xMove = max_step(unwindAccumulator[0]);
    int yMove = max_step(unwindAccumulator[1]);

    Mouse.move(xMove, yMove);
    unwindAccumulator[0] += xMove;
    unwindAccumulator[1] += yMove;
  }
}

StickState *activeStick = nullptr;

// Update mouse motion state and send HID reports.
void sendMouse() {
  if (activeStick) { // are we in an active move?
    if (activeStick->checkDeadzone()) { // did it stop?
      activeStick->deactivate();
      activeStick = nullptr;
    }
    else { // still active, so keep moving.
      activeStick->moveActiveMotion(false);
    }
  }
  else {
    for (StickState & stick : sticks) { // check for the first stick out of its deadzone
      if (!stick.checkDeadzone()) {
        activeStick = &stick;
        activeStick->activate(); // bust a move.
        activeStick->moveActiveMotion(true);
        return;
      }
    }
  }
}

// typedef for a button activation callback.
using button_func = std::function<void(int, bool)>;

// button does nothing.
void null_button(int, bool) {}

void macro_button(int button, bool pressed) {
  const auto macro = button - 2;
  buttonMacros[macro](pressed);
}

// basic button callback that simply advances the active stick mode.
void advance_mode(int button, bool pressed) {
  if (!pressed) return; // only fire on press-down

  if (sticks[button].stickActive) return; // don't change the mode on the active stick.
  sticks[button].advanceActiveMode();
};

const button_func button_clicked[] = {
  advance_mode, // stick buttons
  advance_mode,

  macro_button,
  macro_button,
  macro_button,
  macro_button,
  macro_button,
  macro_button
};

// update buttons and call callbacks when they're pressed.
void updateButtons() {
  for (int i = 0; i < n_buttons; i++) {
    buttons[i].update();

    if (buttons[i].fell()) {
      if constexpr (serial_status_reports && serial_buttons) {
        Serial.print("BP ");
        Serial.println(i);
      }

      buttonState[i] = true;
      button_clicked[i](i, true);

      buttonColorCache[i] = ledStrip.getPixelColor(buttonLEDMap[i]);
      ledStrip.setPixelColor(buttonLEDMap[i], 0);
    }
    else if (buttons[i].rose()) {
      if constexpr (serial_status_reports && serial_buttons) {
        Serial.print("BR ");
        Serial.println(i);
      }

      ledStrip.setPixelColor(buttonLEDMap[i], buttonColorCache[i]);

      buttonState[i] = false;
      button_clicked[i](i, false);
    }
  }
}

/**
 * ARDUINO HOOKS
*/

void setup() {
  if constexpr (serial_status_reports) {
    Serial.begin(38400);
  }

  // set up button with the Bounce library.
  for (int i = 0; i < n_buttons; i++) {
    buttons[i].attach(buttonPins[i], INPUT_PULLUP);
    buttons[i].interval(button_debounce_interval);
  }

  if constexpr (center_on_startup) {
    // calibrate stick centers.
    readSticks();
    for (int i = 0; i < n_axes; i++) {
      axisExtents[i][1] = axisValues[i];
    }
  }

  pinMode(LED_BUILTIN, OUTPUT);

  // initialize RGB LEDs
  ledStrip.begin();
  ledStrip.fill(0x50, 0, 9);
  ledStrip.setBrightness(20);

  sticks[0].updateStickLED();
  sticks[1].updateStickLED();

  for (int i = 0; i < macroKeyCount; i++) {
    ledStrip.setPixelColor(3 + i, macroColors[i]);
  }

  ledStrip.show();
}

Metro joystickMetro(joystick_interval);
Metro mouseMetro(mouse_interval);
Metro serialMetro(serial_interval);

void loop() {
  digitalWrite(LED_BUILTIN, false);
  readSticks();
  updateButtons();
  normalizeSticks();

  #ifdef SUPPORT_RAT_DRIVER
  uint8_t hidbuf[64];
  if (RawHID.recv(hidbuf, 0)) {
    Serial.println((char *) hidbuf);
  }
  #endif

  if constexpr (send_joystick_hid) {
    if (joystickMetro.check()) {
      sendJoystick();
      joystickMetro.reset();
    }
  }

  if (mouseMetro.check()) {
    sendMouse();
    mouseMetro.reset();
  }

  if constexpr (serial_status_reports) {
    if (serialMetro.check()) {

      if constexpr (serial_raw_axes) {
        Serial.print("AXES ");
        for (auto const& a : axisValues) {
          Serial.print(a);
          Serial.print(" ");
        }
        Serial.print("\n");
      }
      
      if constexpr (serial_norm_axes) {
        Serial.print("NORM ");
        for (auto const& a : normalizedAxes) {
          Serial.print((int) (a * 100));
          Serial.print(" ");
        }
        Serial.print("\n");
        serialMetro.reset();
      }
    }
  }

  ledStrip.show();
  digitalWrite(LED_BUILTIN, true);
}

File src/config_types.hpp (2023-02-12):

#pragma once
#include "helpers.hpp"
#include <array>

// Options for how the stick will move the mouse, scroll wheel, etc.
enum class MovementMode {
  REWIND, // do a motion then unwind the cursor position when the stick is released
  STUTTER, // move, then unwind after `stutter_step` movement, then repeat, until the stick is released.
  SIMPLE, // don't unwind at all, just move the cursor
  CHASE, // move, then activate keyboard command, continuously. This doesn't work that great, honestly.
  SCROLL // translate stick movements into vertical and horizontal scroll wheel events.
};

// A curve used to interpolate stick positions.
// There's not much point increasing the size (resolution) of the curve. The joysticks aren't sensitive enough to benefit.
using StickCurve = std::array<int16_t, 10>;

constexpr auto INVERT_AXIS = -1;
constexpr auto NO_INVERT_AXIS = 1;
constexpr auto NULL_AXIS = 0;

// Create a new StickMode and add it to `stickModes` in main to create a new operation mode for a stick.
struct StickMode {
  const MovementMode move; // which movement mode?
  const StickCurve& curve; // how fast and on what curve to move the mouse or wheel?
  const uint32_t indicator = rgb(255, 0, 0); // what color should the indicator be?
  const bool activeButtons[3] = {false, false, false}; // which buttons to press? left, middle, right

  const int activeKey = 0; // which key to hold down during mouse motion
  
  const int8_t horDir = INVERT_AXIS; // set positive (1) or inverted motion (-1), or 0 for null axis.
  const int8_t vertDir = INVERT_AXIS; // same as horDir.

  const int chaseKey = 0; // key to press after each motion step to "chase"
  const int chaseMods = 0; // modifiers to press along with the chase key.

  const int motionThreshold = 1; // how many pixels of movement are required to trigger mouse motion?


  constexpr bool hasButtons() const {
    return activeButtons[0] || activeButtons[1] || activeButtons[2];
  }

  constexpr bool hasKey() const {
    return activeKey;
  }
};


// build a curve of the form `maxSpeed * x^(e*expCoef)`.
// this is a basic "expo" function like found on RC controller sticks.
// set expCoef to 0.4 to get a more-or-less linear curve.
constexpr StickCurve make_curve(float maxSpeed, float expCoef = 0.4f) {
  StickCurve retval = {};
  float step = 1.0f / (retval.size() - 1);
  for (unsigned int i = 0; i < retval.size(); i++) {
    retval[i] = exp_entry(expCoef, i * step, maxSpeed);
  }
  return retval;
}


// This is not very interesting, just c++ nonsense to make a compile-time array.
template <int STICK_A_MODES, int STICK_B_MODES>
struct ModeMap {
  const std::array<StickMode, STICK_A_MODES + STICK_B_MODES> modes;
  static constexpr int aModesCount = STICK_A_MODES, bModesCount = STICK_B_MODES;

  constexpr ModeMap(std::array<StickMode, STICK_A_MODES> const& aModes, std::array<StickMode, STICK_B_MODES> const& bModes) : modes(detail::concatArray(aModes, bModes)) {}

  constexpr int count(int stick) const {
    if (stick == 0) return STICK_A_MODES;
    return STICK_B_MODES;
  }

  constexpr StickMode const& getMode(int stick, int modeIndex) const {
    if (stick == 0) {
      return modes[modeIndex];
    }
    else {
      return modes[STICK_A_MODES + modeIndex];
    }
  }
};

template <typename T1, typename T2>
constexpr auto declare_mode_map(T1 const& aModes, T2 const& bModes) {
    return ModeMap<aModes.size(), bModes.size()>(aModes, bModes);
}

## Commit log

2022-04-04 Flipped the pan stick inputs.
    [main.cpp]
2022-04-04 Added readme and a little more configuration.
    [rev_a.brd, rev_a.sch]
2022-04-05 Finished a rev a, but it's enormous.
    [rev_a.brd, rev_a.sch]
2022-04-06 Gonna rewrite a bit.
    [rev_b.brd, rev_b.sch]
2022-04-06 Buttons reporting now.
2022-04-06 Gottta do some interpolation, hope the float doesn't kill me.
    [rev_c.brd, rev_c.sch]
2022-04-06 Added comments, changed USB device name, improved scrolling.
2022-04-06 Upgraded to gcc 9.3 for that good constexpr, included arm math library.
2022-04-07 Trying again on the circuit, fiddling with settings for nice scrolling in eagle.
    [rev_d.brd, rev_d.sch]
2022-04-07 Switched the expo tables from floats to shorts for a bit of performance and memory savings.
    [main.cpp]
2022-04-10 Updated docs, also sent `rev_d` to production.
    [rev_e.brd, rev_e.sch]
2022-04-13 Working through feature suggestions.
    [rev_d.brd, rev_d.sch]
2022-04-17 Working on raw hid endpoint for feedback from system.
    [macro_rat.brd, macro_rat.sch, simple_rat.brd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]
2022-04-22 Circuit boards are supposed to show up today.
2022-04-24 Lots of progress in hardware and software.
    [deluxe_sticks.scad, macro_rat.brd, macro_rat.sch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]
2022-04-24 Added builtin LED status/processing monitor.
2023-02-12 I don't remember, honestly. It's been a year since I worked on this.
    [deluxe_sticks.scad, macro_rat.sch]
2023-02-12 Much hacking, but got LEDs working.

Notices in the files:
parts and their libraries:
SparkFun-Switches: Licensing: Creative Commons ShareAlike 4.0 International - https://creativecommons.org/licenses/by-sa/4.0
